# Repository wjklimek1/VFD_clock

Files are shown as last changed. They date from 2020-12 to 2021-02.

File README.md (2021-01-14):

# VFD_clock
Clock with VFD display based on STM32 MCU. Displays time, date and temperature.

As a display i used an old VFD tube IW-18 (IV-18). Device displays time (hours, minutes and seconds), date and temperature. Clock is based on STM32F103C8T6 microcontroller and it was programmed with HAL libraries. To boost voltage to required level I used popular SX1308 step-up IC.To power VFD display filament with alternating current i used L293d H-bridge with single transistor serving as simple NOT gate.

Schematic and PCB were designed using KiCad. You can find schematic in PDF format in PDFs folder of this repository.

Sensors used in the project:
RTC - DS3231 I2C real time clock

DS18B20 - 1-Wire temperature sensor (not utilized in software yet)
DHT11   - digital relative humidity sensor (not utilized in software yet)

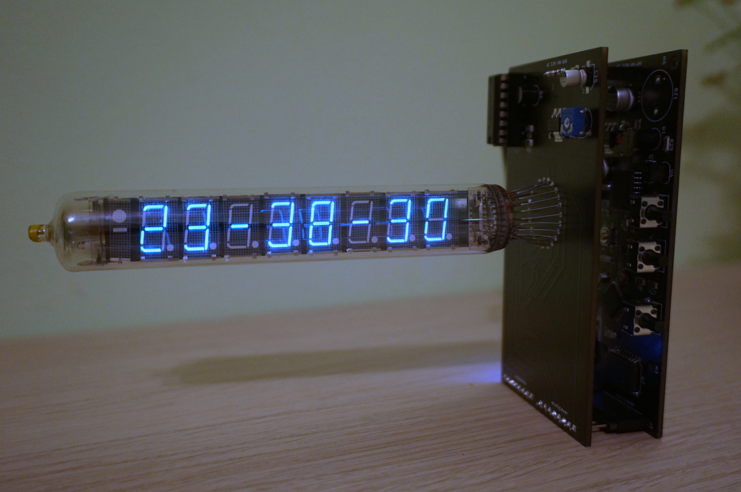
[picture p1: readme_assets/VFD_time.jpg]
VFD clock displaying time


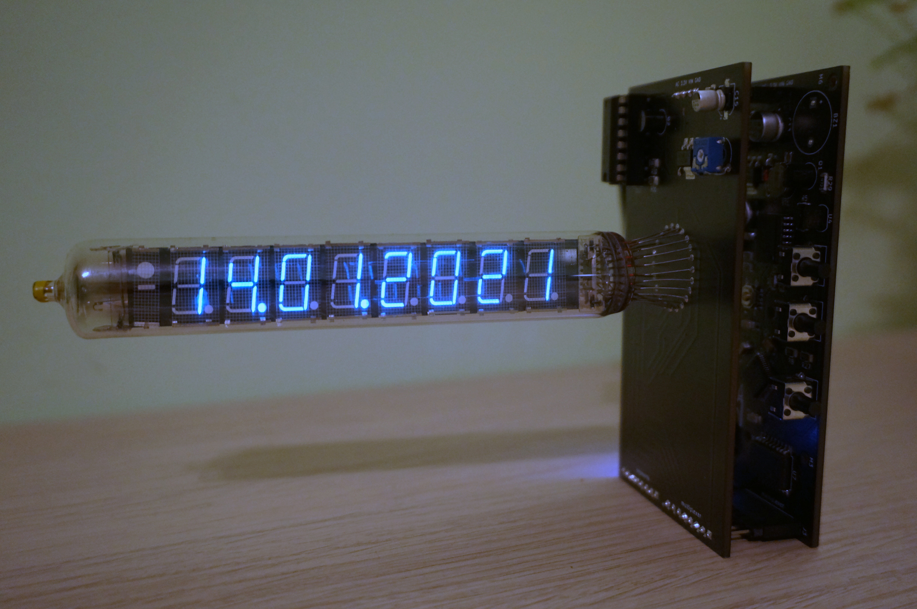
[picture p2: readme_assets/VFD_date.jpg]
VFD clock displaying date


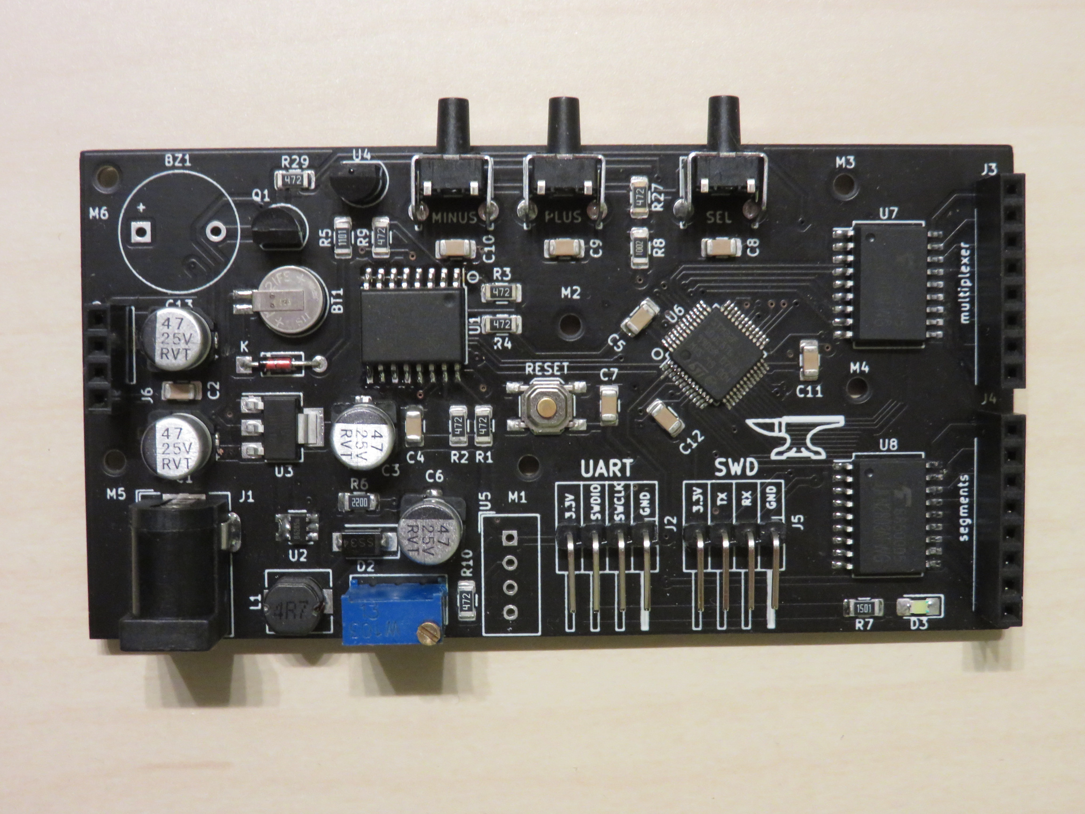
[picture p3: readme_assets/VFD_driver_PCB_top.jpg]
VFD clock driver PCB


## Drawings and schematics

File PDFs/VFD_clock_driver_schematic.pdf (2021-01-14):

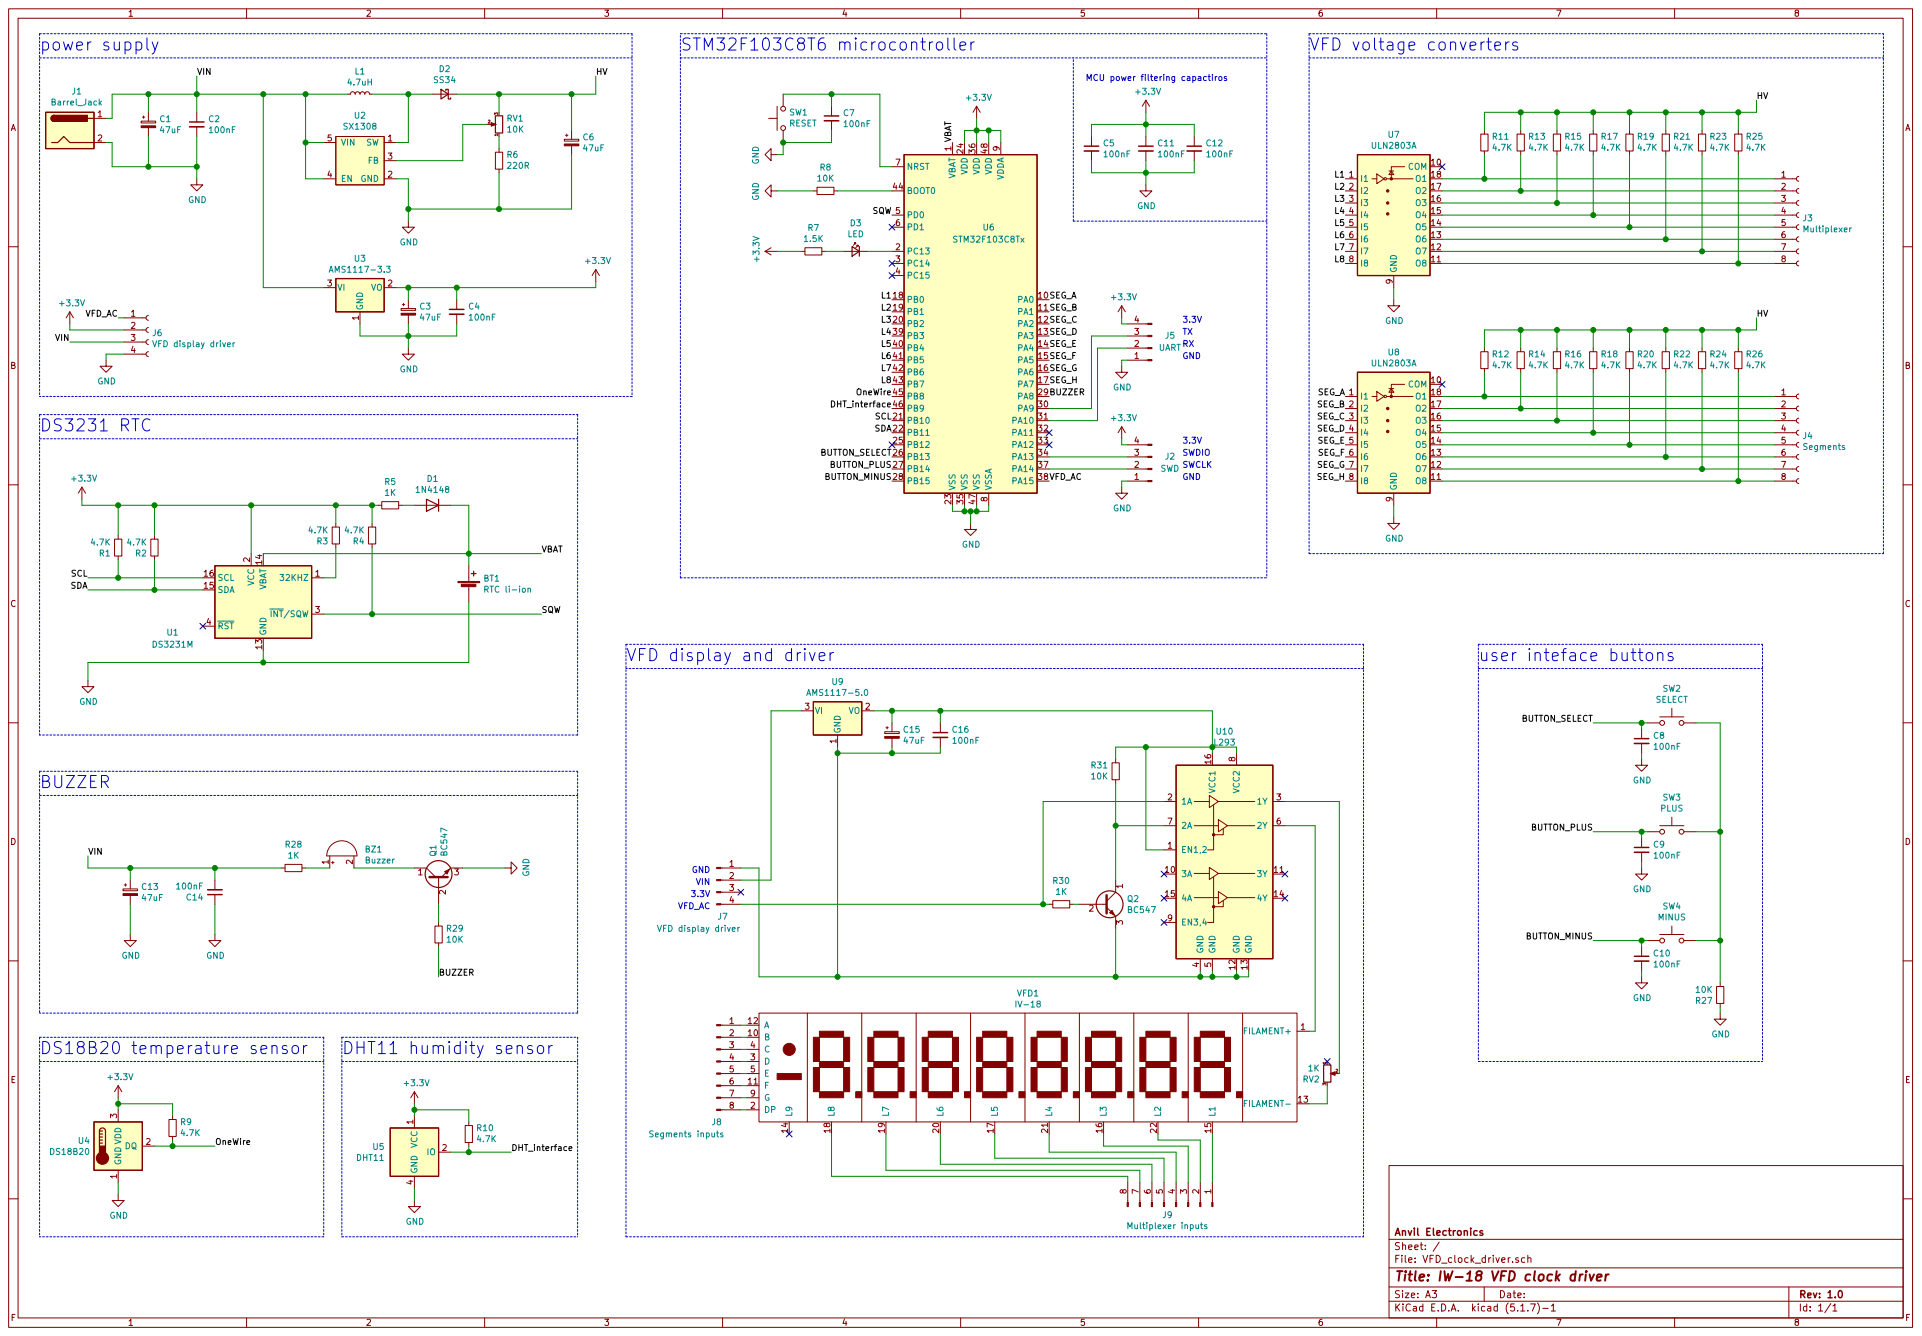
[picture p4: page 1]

MCU power filtering capactiros

1 VDD 24 VDD 36 VDD 48 VDDA

9 VSS 23 VSS 35 VSS 47 VSSA

File: VFD_clock_driver.sch Sheet: / Anvil Electronics

Id: 1/1 Title: IW-18 VFD clock driver

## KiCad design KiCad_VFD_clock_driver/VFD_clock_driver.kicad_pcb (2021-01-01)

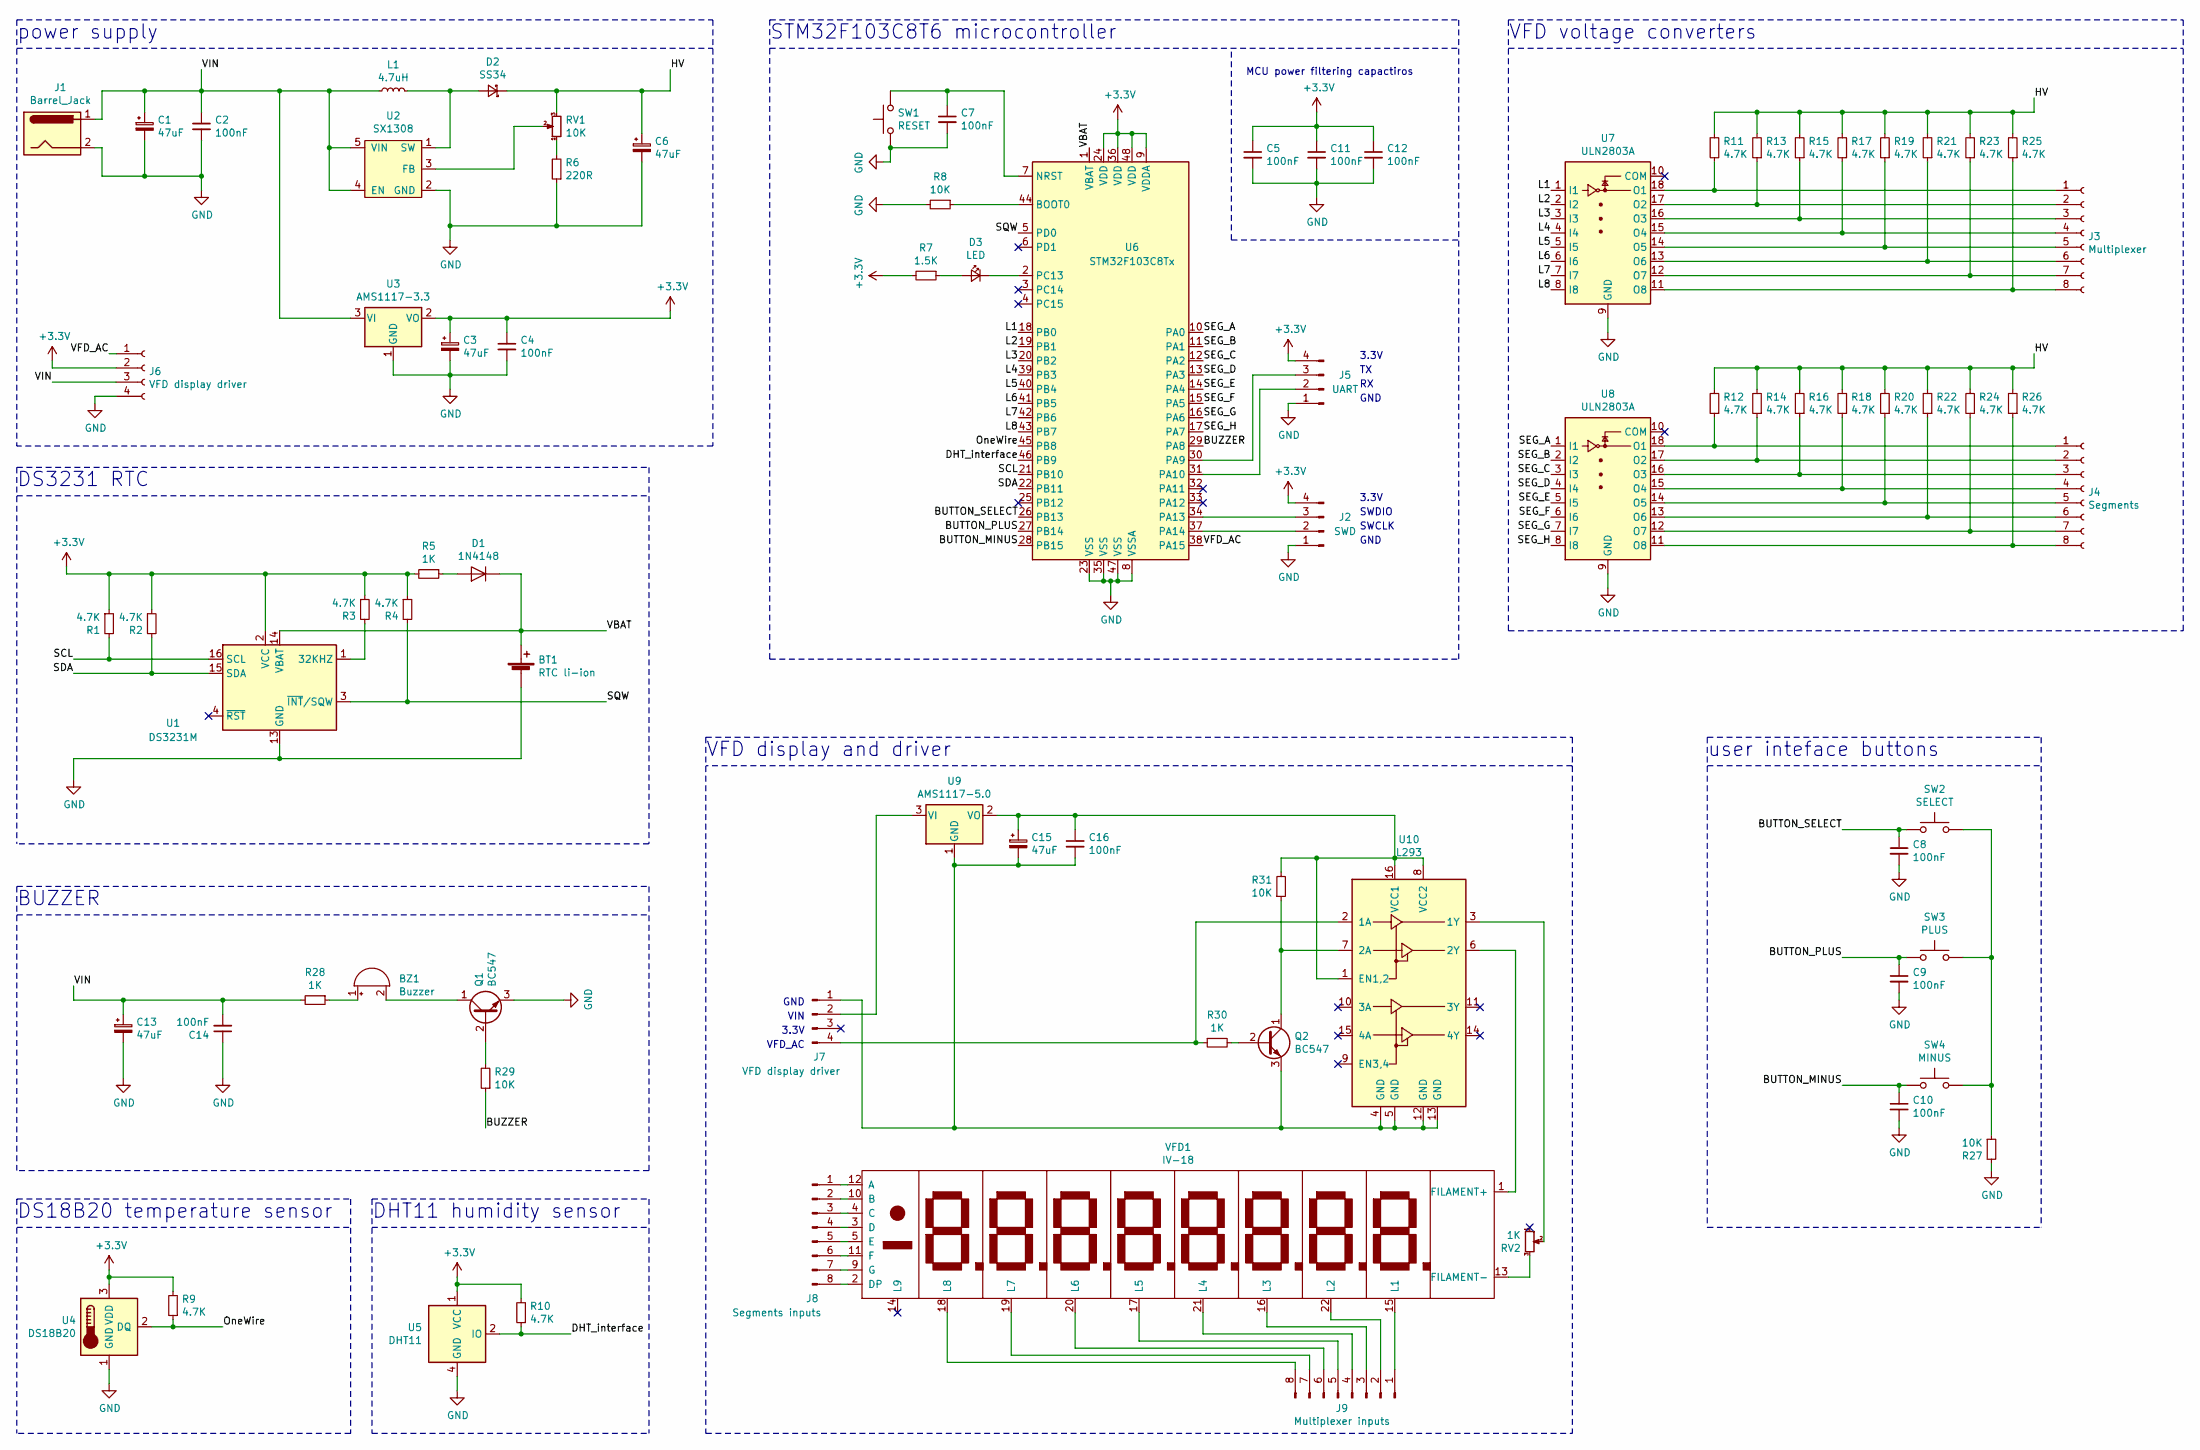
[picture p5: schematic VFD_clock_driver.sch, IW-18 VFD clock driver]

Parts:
BT1: RTC li-ion; BatteryHolder_Seiko_MS621F
BZ1: Buzzer; Buzzer_12x9.5RM7.6
C1, C3, C6, C13, C15: 47uF; CP_Elec_6.3x4.5
C2, C4, C5, C7, C8, C9, C10, C11, C12, C14, C16: 100nF; C_1206_3216Metric
D1: 1N4148; D_DO-35_SOD27_P7.62mm_Horizontal
D2: SS34; D_SMA
D3: LED; D_1206_3216Metric_Pad1.42x1.75mm_HandSolder
J1: Barrel_Jack; BarrelJack
J2: SWD; PinHeader_1x04_P2.54mm_Horizontal
J3: Multiplexer; PinSocket_1x08_P2.54mm_Vertical
J4: Segments; PinSocket_1x08_P2.54mm_Vertical
J5: UART; PinHeader_1x04_P2.54mm_Horizontal
J6: VFD display driver; PinSocket_1x04_P2.54mm_Vertical
J7: VFD display driver; PinHeader_1x04_P2.54mm_Vertical
J8: Segments inputs; PinHeader_1x08_P2.54mm_Vertical
J9: Multiplexer inputs; PinHeader_1x08_P2.54mm_Vertical
L1: 4.7uH; L_6.3x6.3_H3
Q1, Q2: BC547; TO-92_Inline
R1, R2, R3, R4, R9, R10, R11, R12, R13, R14, R15, R16, R17, R18, R19, R20, R21, R22, R23, R24, R25, R26: 4.7K; R_1206_3216Metric
R5, R28, R30: 1K; R_1206_3216Metric
R6: 220R; R_1206_3216Metric
R7: 1.5K; R_1206_3216Metric
R8, R27, R29, R31: 10K; R_1206_3216Metric
RV1: 10K; Potentiometer_Bourns_3296W_Vertical
RV2: 1K; Potentiometer_Piher_PT-6-V_Vertical_Hole
SW1: RESET; SW_SPST_TL3342
SW2: SELECT; SW_Tactile_SPST_Angled_PTS645Vx83-2LFS
SW3: PLUS; SW_Tactile_SPST_Angled_PTS645Vx83-2LFS
SW4: MINUS; SW_Tactile_SPST_Angled_PTS645Vx83-2LFS
U1: DS3231M; SOIC-16W_7.5x10.3mm_P1.27mm
U2: SX1308; SOT-23-6_Handsoldering
U3: AMS1117-3.3; SOT-223-3_TabPin2
U4: DS18B20; TO-92_Inline
U5: DHT11; Aosong_DHT11_5.5x12.0_P2.54mm
U6: STM32F103C8Tx; LQFP-48_7x7mm_P0.5mm
U7, U8: ULN2803A; SOP-18_7x12.5mm_P1.27mm
U9: AMS1117-5.0; SOT-223-3_TabPin2
U10: L293; DIP-16_W7.62mm
VFD1: IV-18

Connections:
+3V3: C3.1, C4.1, C5.1, C11.1, C12.1, J2.4, J5.4, J6.2, R1.1, R2.1, R3.1, R4.1, R5.2, R7.2, R9.2, R10.2, U1.2 (VCC), U3.2 (VO), U4.3 (VDD), U5.1 (VCC), U6.9 (VDDA), U6.24 (VDD), U6.36 (VDD), U6.48 (VDD)
/BUTTON_MINUS: C10.1, SW4.1, U6.28 (PB15)
/BUTTON_PLUS: C9.1, SW3.1, U6.27 (PB14)
/BUTTON_SELECT: C8.1, SW2.1, U6.26 (PB13)
/BUZZER: R29.1, U6.29 (PA8)
/DHT_interface: R10.1, U5.2 (IO), U6.46 (PB9)
/HV: C6.1, D2.1 (K), R11.2, R12.2, R13.2, R14.2, R15.2, R16.2, R17.2, R18.2, R19.2, R20.2, R21.2, R22.2, R23.2, R24.2, R25.2, R26.2, RV1.3
/L1: U6.18 (PB0), U7.1 (I1)
/L2: U6.19 (PB1), U7.2 (I2)
/L3: U6.20 (PB2), U7.3 (I3)
/L4: U6.39 (PB3), U7.4 (I4)
/L5: U6.40 (PB4), U7.5 (I5)
/L6: U6.41 (PB5), U7.6 (I6)
/L7: U6.42 (PB6), U7.7 (I7)
/L8: U6.43 (PB7), U7.8 (I8)
/OneWire: R9.1, U4.2 (DQ), U6.45 (PB8)
/SCL: R1.2, U1.16 (SCL), U6.21 (PB10)
/SDA: R2.2, U1.15 (SDA), U6.22 (PB11)
/SEG_A: U6.10 (PA0), U8.1 (I1)
/SEG_B: U6.11 (PA1), U8.2 (I2)
/SEG_C: U6.12 (PA2), U8.3 (I3)
/SEG_D: U6.13 (PA3), U8.4 (I4)
/SEG_E: U6.14 (PA4), U8.5 (I5)
/SEG_F: U6.15 (PA5), U8.6 (I6)
/SEG_G: U6.16 (PA6), U8.7 (I7)
/SEG_H: U6.17 (PA7), U8.8 (I8)
/SQW: R4.2, U1.3 (~INT~/SQW), U6.5 (PD0)
/VBAT: BT1.1 (+), D1.1 (K), U1.14 (VBAT), U6.1 (VBAT)
/VFD_AC: J6.1, U6.38 (PA15)
/VIN: C1.1, C2.1, C13.1, C14.2, J1.1, J6.3, L1.1, R28.2, U2.4 (EN), U2.5 (VIN), U3.3 (VI)
GND: BT1.2 (-), C1.2, C2.2, C3.2, C4.2, C5.2, C6.2, C7.2, C8.2, C9.2, C10.2, C11.2, C12.2, C13.2, C14.1, J1.2, J2.1, J5.1, J6.4, Q1.3 (E), R6.1, R8.2, R27.2, SW1.1, U1.5 (GND), U1.6 (GND), U1.7 (GND), U1.8 (GND), U1.9 (GND), U1.10 (GND), U1.11 (GND), U1.12 (GND), U1.13 (GND), U2.2 (GND), U3.1 (GND), U4.1 (GND), U5.4 (GND), U6.8 (VSSA), U6.23 (VSS), U6.35 (VSS), U6.47 (VSS), U7.9 (GND), U8.9 (GND)
unnamed: BZ1.1 (-), R28.1
unnamed: BZ1.2 (+), Q1.1 (C)
unnamed: C7.1, SW1.2, U6.7 (NRST)
unnamed: C15.1, C16.1, R31.2, U9.2 (VO), U10.1 (EN1,2), U10.8 (VCC2), U10.16 (VCC1)
unnamed: C15.2, C16.2, J7.1, Q2.3 (E), U9.1 (GND), U10.4 (GND), U10.5 (GND), U10.12 (GND), U10.13 (GND)
unnamed: D1.2 (A), R5.1
unnamed: D2.2 (A), L1.2, U2.1 (SW)
unnamed: D3.1 (K), U6.2 (PC13)
unnamed: D3.2 (A), R7.1
unnamed: J2.2, U6.37 (PA14)
unnamed: J2.3, U6.34 (PA13)
unnamed: J3.1, R11.1, U7.18 (O1)
unnamed: J3.2, R13.1, U7.17 (O2)
unnamed: J3.3, R15.1, U7.16 (O3)
unnamed: J3.4, R17.1, U7.15 (O4)
unnamed: J3.5, R19.1, U7.14 (O5)
unnamed: J3.6, R21.1, U7.13 (O6)
unnamed: J3.7, R23.1, U7.12 (O7)
unnamed: J3.8, R25.1, U7.11 (O8)
unnamed: J4.1, R12.1, U8.18 (O1)
unnamed: J4.2, R14.1, U8.17 (O2)
unnamed: J4.3, R16.1, U8.16 (O3)
unnamed: J4.4, R18.1, U8.15 (O4)
unnamed: J4.5, R20.1, U8.14 (O5)
unnamed: J4.6, R22.1, U8.13 (O6)
unnamed: J4.7, R24.1, U8.12 (O7)
unnamed: J4.8, R26.1, U8.11 (O8)
unnamed: J5.2, U6.31 (PA10)
unnamed: J5.3, U6.30 (PA9)
unnamed: J7.2, U9.3 (VI)
unnamed: J7.4, R30.1, U10.2 (1A)
unnamed: J8.1, VFD1.12 (A)
unnamed: J8.2, VFD1.10 (B)
unnamed: J8.3, VFD1.4 (C)
unnamed: J8.4, VFD1.3 (D)
unnamed: J8.5, VFD1.5 (E)
unnamed: J8.6, VFD1.11 (F)
unnamed: J8.7, VFD1.9 (G)
unnamed: J8.8, VFD1.2 (DP)
unnamed: J9.1, VFD1.15 (L1)
unnamed: J9.2, VFD1.22 (L2)
unnamed: J9.3, VFD1.16 (L3)
unnamed: J9.4, VFD1.21 (L4)
unnamed: J9.5, VFD1.17 (L5)
unnamed: J9.6, VFD1.20 (L6)
unnamed: J9.7, VFD1.19 (L7)
unnamed: J9.8, VFD1.18 (L8)
unnamed: Q1.2 (B), R29.2
unnamed: Q2.1 (C), R31.1, U10.7 (2A)
unnamed: Q2.2 (B), R30.2
unnamed: R3.2, U1.1 (32KHZ)
unnamed: R6.2, RV1.1
unnamed: R8.1, U6.44 (BOOT0)
unnamed: R27.1, SW2.2, SW3.2, SW4.2
unnamed: RV1.2, U2.3 (FB)
unnamed: RV2.2, U10.3 (1Y)
unnamed: RV2.3, VFD1.13 (FILAMENT-)
unnamed: U10.6 (2Y), VFD1.1 (FILAMENT+)

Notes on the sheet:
3.3V
SWDIO
SWCLK
GND
DS3231 RTC
power supply
DS18B20 temperature sensor
VFD voltage converters
user inteface buttons
DHT11 humidity sensor
STM32F103C8T6 microcontroller
MCU power filtering capactiros
BUZZER
VIN
VFD_AC
VFD display and driver

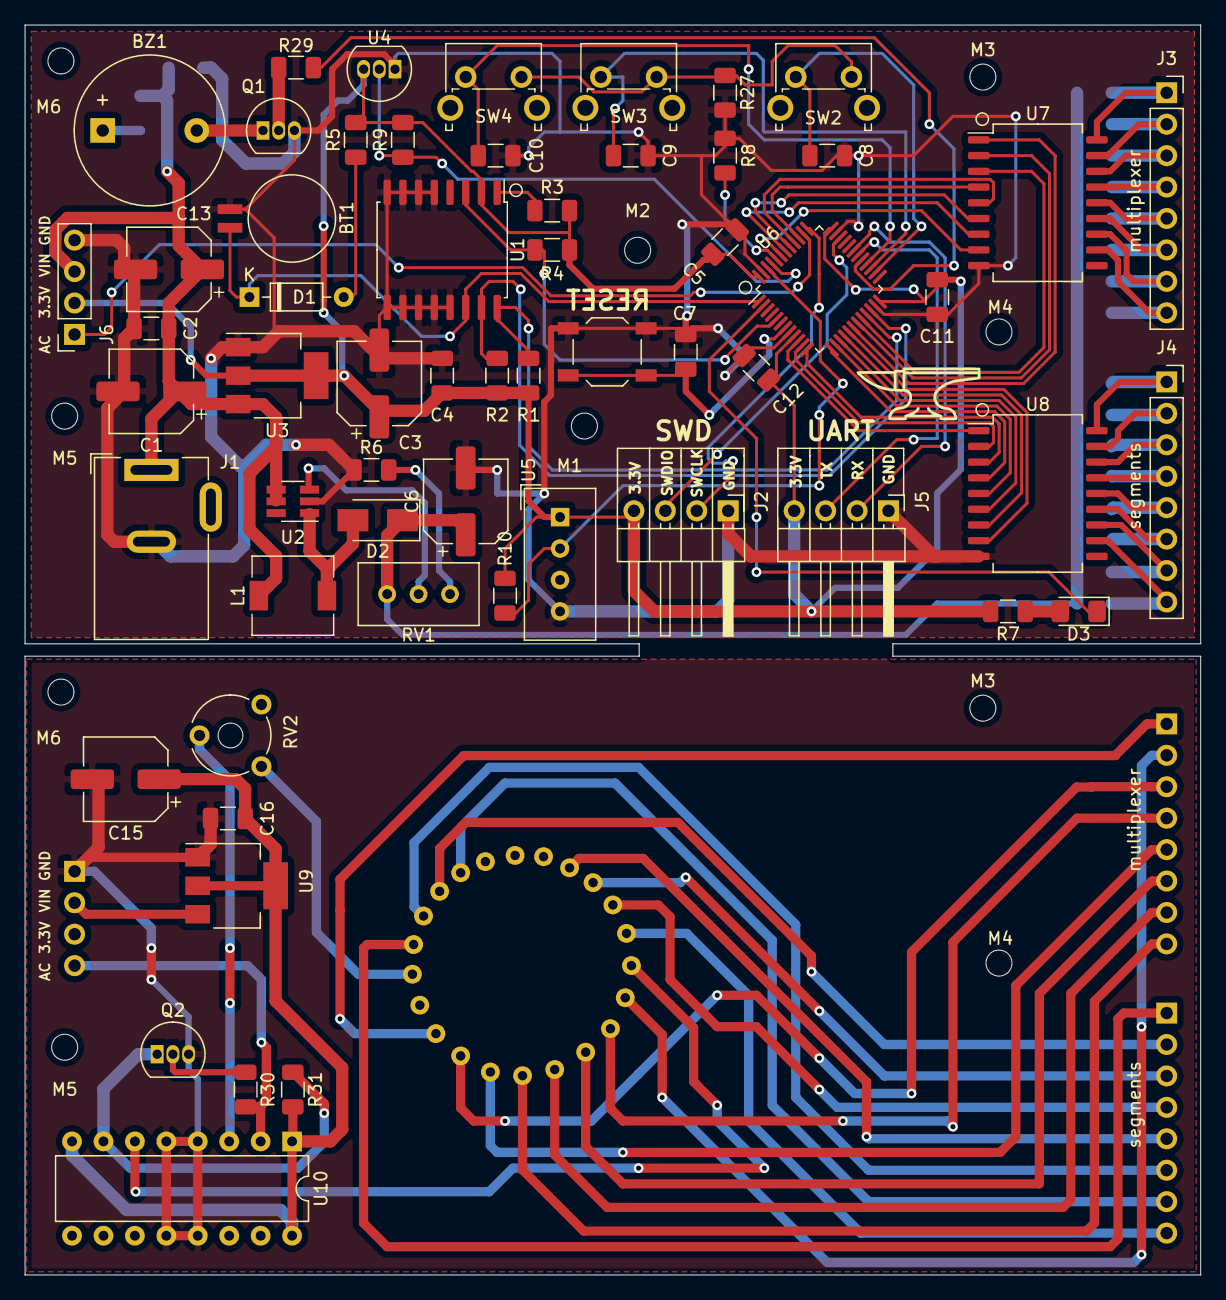
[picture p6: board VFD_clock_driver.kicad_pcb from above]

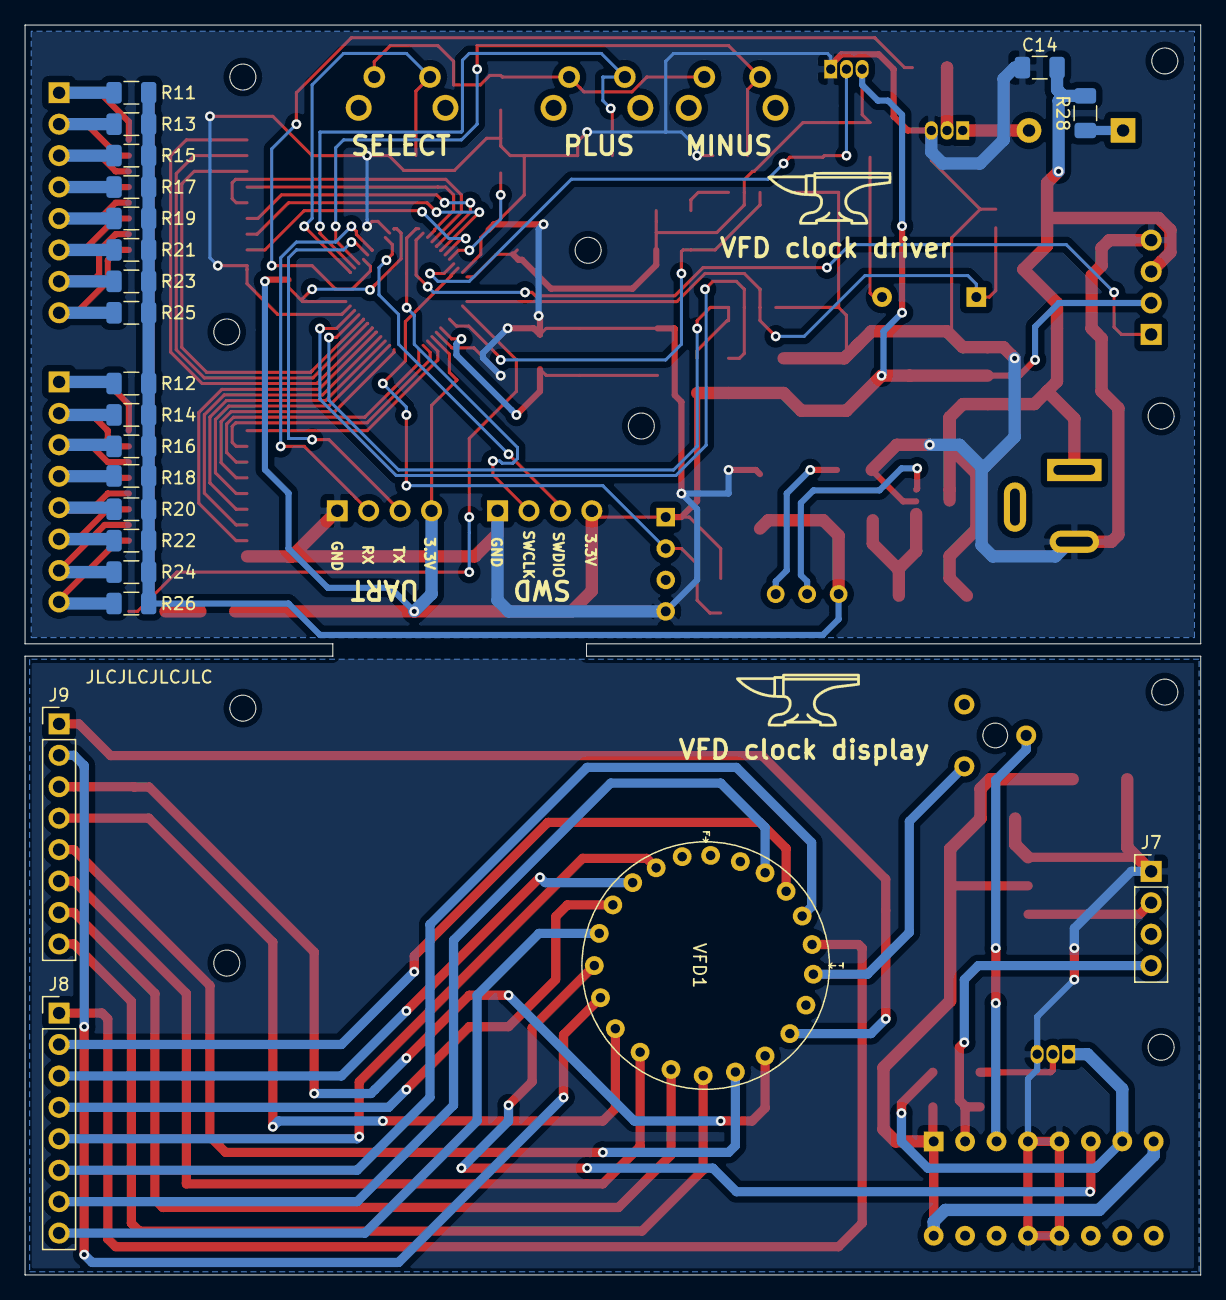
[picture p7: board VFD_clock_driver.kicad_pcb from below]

Board: 2 copper layers, 95.0 x 101.0 mm, 91 parts (22 on the bottom side), 89 nets.

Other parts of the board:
M1, M2, M3, M3#2, M4, M4#2, M5, M5#2, M6, M6#2: MountingHole_2.1mm

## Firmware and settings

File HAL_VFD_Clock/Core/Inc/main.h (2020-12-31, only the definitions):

#define LED_Pin GPIO_PIN_13
#define LED_GPIO_Port GPIOC
#define SQW_Pin GPIO_PIN_0
#define SQW_GPIO_Port GPIOD
#define SQW_EXTI_IRQn EXTI0_IRQn
#define SEG_A_Pin GPIO_PIN_0
#define SEG_A_GPIO_Port GPIOA
#define SEG_B_Pin GPIO_PIN_1
#define SEG_B_GPIO_Port GPIOA
#define SEG_C_Pin GPIO_PIN_2
#define SEG_C_GPIO_Port GPIOA
#define SEG_D_Pin GPIO_PIN_3
#define SEG_D_GPIO_Port GPIOA
#define SEG_E_Pin GPIO_PIN_4
#define SEG_E_GPIO_Port GPIOA
#define SEG_F_Pin GPIO_PIN_5
#define SEG_F_GPIO_Port GPIOA
#define SEG_G_Pin GPIO_PIN_6
#define SEG_G_GPIO_Port GPIOA
#define SEG_H_Pin GPIO_PIN_7
#define SEG_H_GPIO_Port GPIOA
#define L1_Pin GPIO_PIN_0
#define L1_GPIO_Port GPIOB
#define L2_Pin GPIO_PIN_1
#define L2_GPIO_Port GPIOB
#define L3_Pin GPIO_PIN_2
#define L3_GPIO_Port GPIOB
#define BUTTON_SELECT_Pin GPIO_PIN_13
#define BUTTON_SELECT_GPIO_Port GPIOB
#define BUTTON_SELECT_EXTI_IRQn EXTI15_10_IRQn
#define BUTTON_PLUS_Pin GPIO_PIN_14
#define BUTTON_PLUS_GPIO_Port GPIOB
#define BUTTON_PLUS_EXTI_IRQn EXTI15_10_IRQn
#define BUTTON_MINUS_Pin GPIO_PIN_15
#define BUTTON_MINUS_GPIO_Port GPIOB
#define BUTTON_MINUS_EXTI_IRQn EXTI15_10_IRQn
#define BUZZER_Pin GPIO_PIN_8
#define BUZZER_GPIO_Port GPIOA
#define VFD_AC_Pin GPIO_PIN_15
#define VFD_AC_GPIO_Port GPIOA
#define L4_Pin GPIO_PIN_3
#define L4_GPIO_Port GPIOB
#define L5_Pin GPIO_PIN_4
#define L5_GPIO_Port GPIOB
#define L6_Pin GPIO_PIN_5
#define L6_GPIO_Port GPIOB
#define L7_Pin GPIO_PIN_6
#define L7_GPIO_Port GPIOB
#define L8_Pin GPIO_PIN_7
#define L8_GPIO_Port GPIOB
#define DHT_interface_Pin GPIO_PIN_8
#define DHT_interface_GPIO_Port GPIOB
#define OneWire_Pin GPIO_PIN_9
#define OneWire_GPIO_Port GPIOB

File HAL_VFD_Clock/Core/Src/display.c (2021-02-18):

#include "display.h"

/*
 * @brief Outputs character mask on segments
 *
 * Bits in symbol_mask byte represents powered segments in following order:
 * ABCDEFGH
 *
 * @param[in]
 * symbol_mask 8bit mask of GPIO pins states
 */
void dispChar(uint8_t symbol_mask)
{
	SEGMENTS_GPIO_Port->BSRR = ~symbol_mask;
	SEGMENTS_GPIO_Port->BSRR = symbol_mask << 16u;
}

/*
 * @brief Activates displays in VFD tube
 *
 * bits in displays_mask byte represents powered displays in following order:
 * LSB - far right display
 * MSB - far left display
 *
 * @param[in] displays_mask 8bit mask where one bit is 1 and others are 0. Active bit codes number of activated display.
 */
void selectDisplay(uint8_t displays_mask)
{
	DISPLAYS_GPIO_Port->BSRR = ~displays_mask;
	DISPLAYS_GPIO_Port->BSRR = displays_mask << 16u;
}

/*
 * @brief Multiplexer function that is supposed to be used in regular intervals triggered by timer.
 *
 * It iterates through array of masks of characters that will be displayed. In a single cycle only one display is
 * activated. After 8 cycles it starts again from beginning of masks array.
 *
 * blink_timer is incremented every cycle by 64 and if it is lower than half of its max value,
 * blink_mask is taken into consideration and display which corresponding bit in blink_mask is 0 will be turned off.
 */
void multiplexerSequence()
{
	static uint8_t i = 0;              //number of currently active display
	static uint16_t blink_timer = 0;   //

	dispChar(tab_to_display[i]);        //set GPIOs to states described in corresponding mask in array
	if(blink_timer > (0xFFFF / 2))      //decide if digit should blink
		selectDisplay(1U << i);         //display digit normally
	else
		selectDisplay((1U << i) & blink_mask); //if digit is masked by bit in blink_mask
	                                           //and blink timer hasn't elapsed half of its max value, disable display

	++i;                //increment number of currently active display
	blink_timer += 64;  //increment blink timer

	if(i >= 8)          //if last display was handled, move back to first one
		i = 0;
}

/*
 * @brief Converts ASCII character to corresponding 7 segment display bitmask
 *
 * If character is undefined, it returns empty mask (space).
 *
 * @param[in] inputChar ASCII character
 * @returns 8bit bitmask for 7 segment display
 */

uint8_t charToBitmask(char inputChar)
{
	switch (inputChar)
	{
		// numbers masks
		case '1':
			return mask_1;
		case '2':
			return mask_2;
		case '3':
			return mask_3;
		case '4':
			return mask_4;
		case '5':
			return mask_5;
		case '6':
			return mask_6;
		case '7':
			return mask_7;
		case '8':
			return mask_8;
		case '9':
			return mask_9;
		case '0':
			return mask_0;

			//special masks
		case ' ':
			return mask_space;
		case '-':
			return mask_hypen;
		case '*':
			return mask_degree;

			//characters masks
		case 'a':
			return mask_A;
		case 'b':
			return mask_B;
		case 'c':
			return mask_C;
		case 'd':
			return mask_D;
		case 'e':
			return mask_E;
		case 'f':
			return mask_F;
		case 'h':
			return mask_H;
		case 'i':
			return mask_I;
		case 'j':
			return mask_J;
		case 'l':
			return mask_L;
		case 'o':
			return mask_O;
		case 'p':
			return mask_P;
		case 'r':
			return mask_R;
		case 's':
			return mask_S;
		case 't':
			return mask_T;
		case 'u':
			return mask_U;
		default:
			return 0;
	}
}

/*
 * @brief Converts single digit to bitmask
 *
 * @param[in] digit single digit that will be converted to corresponding mask
 */
uint8_t digitToBitmask(uint8_t digit)
{
	if(digit > 9)
		return 0b00000000;
	switch (digit)
	{
		case 1:
			return mask_1;
		case 2:
			return mask_2;
		case 3:
			return mask_3;
		case 4:
			return mask_4;
		case 5:
			return mask_5;
		case 6:
			return mask_6;
		case 7:
			return mask_7;
		case 8:
			return mask_8;
		case 9:
			return mask_9;
		case 0:
			return mask_0;
		default:
			return 0;
	}
}

/*
 * @brief Converts string to array of bitmasks
 *
 * String has to be null-terminated!
 *
 * @param[in] string pointer to char array
 * @param[in] pos empty spaces to leave in masks array before first character string.
 */
void dispString(const char *string, uint8_t pos)
{
	if(pos > 7)
		return;
	while (*string)
	{
		tab_to_display[pos] = charToBitmask(*string);
		string++;
		pos--;

		if(pos < 0)
			return;
	}
}

/*
 * @brief Displays time in following format: HH-MM-SS
 *
 * @param[in] hour - hour to display. If value is smaller than 0 then only single digit is displayed
 * @param[in] minute - number of minutes to display
 * @param[in] second - number of seconds to display
 */
void displayHour(uint8_t hour, uint8_t minute, uint8_t second)
{
	// hide 0 if hour digit is smaller than 10
	if(hour / 10 == 0)
		tab_to_display[7] = 0b00000000;
	else
		tab_to_display[7] = digitToBitmask(hour / 10);

	tab_to_display[6] = digitToBitmask(hour % 10);
	tab_to_display[5] = mask_hypen;
	tab_to_display[4] = digitToBitmask(minute / 10);
	tab_to_display[3] = digitToBitmask(minute % 10);
	tab_to_display[2] = mask_hypen;
	tab_to_display[1] = digitToBitmask(second / 10);
	tab_to_display[0] = digitToBitmask(second % 10);
}

/*
 * @brief Displays date in following format: DD.MM.YYYY
 *
 * @param[in] day - number of day of month
 * @param[in] month - number of month (1-January ... 12-December)
 * @param[in] year - last two digits of year. Assuming year is after 2000 and before 2100 :D
 */
void displayDate(uint8_t day, uint8_t month, uint8_t year)
{
	// hide 0 if day number is smaller than 10
	if(day / 10 == 0)
		tab_to_display[7] = 0b00000000;
	else
		tab_to_display[7] = digitToBitmask(day / 10);

	tab_to_display[6] = digitToBitmask(day % 10);
	tab_to_display[5] = digitToBitmask(month / 10);
	tab_to_display[4] = digitToBitmask(month % 10);
	tab_to_display[3] = mask_2;
	tab_to_display[2] = mask_0;
	tab_to_display[1] = digitToBitmask(year / 10);
	tab_to_display[0] = digitToBitmask(year % 10);

	tab_to_display[6] |= mask_dot;
	tab_to_display[4] |= mask_dot;
}

/*
 * @brief Displays temperature with two decimal points precision and Celcius degree symbol.
 *
 * Displaying format is: " TT.TT *C "
 *
 * @param[in] temperature to display
 */
void displayTemperature(float temperature)
{
	uint8_t temperature_integer = (uint8_t) temperature;
	uint8_t temperature_fraction = (uint8_t) ((temperature - temperature_integer) * 100);

	tab_to_display[7] = 0;
	tab_to_display[6] = digitToBitmask(temperature_integer / 10);
	tab_to_display[5] = digitToBitmask(temperature_integer % 10);
	tab_to_display[5] |= mask_dot;
	tab_to_display[4] = digitToBitmask(temperature_fraction / 10);
	tab_to_display[3] = digitToBitmask(temperature_fraction % 10);
	tab_to_display[2] = charToBitmask('*');
	tab_to_display[1] = charToBitmask('c');
	tab_to_display[0] = 0;

}

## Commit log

2020-07-14 Initial driver schematic
    + initial driver schematic
    + added project description to readme.md
    + added .gitignore
    [VFD_clock_driver.kicad_pcb, VFD_clock_driver.sch]
2020-11-17 Final driver schematic
    Final driver PCB schematic
    [VFD_clock_driver.kicad_pcb, VFD_clock_driver.sch]
2020-11-17 Buzzer and additional inputs
    + added buzzer with circuitry
    + SQW and UART connected to MCU
    [VFD_clock_driver.kicad_pcb, VFD_clock_driver.sch]
2020-11-19 Power supply section in PCB
    [VFD_clock_driver.kicad_pcb, VFD_clock_driver.sch]
2020-11-19 Final PCB routing
    + updated gitignore with some unnecessary KiCad files
    + final component placement on BCB
    + final routing on PCB
    [VFD_clock_driver.kicad_pcb]
2020-11-19 Silkscreen and planes on PCB
    + final silkscreen on PCB
    + small routing and component location tweaks
    + GND planes on PCB
    [VFD_clock_driver.kicad_pcb]
2020-11-19 VFD tube power connector on BCB
    [VFD_clock_driver.kicad_pcb, VFD_clock_driver.sch]
2020-11-23 External PCB for VFD tube and H-brigde
    + additional PCB for VFD tube with H-bridge
    [VFD_clock_driver.kicad_pcb, VFD_clock_driver.sch]
2020-11-24 Mounting holes on tube PCB
    + added mounting holed on tube PCB, new holes are aligned with old ones in driver PCB
    + fixed misplaced UART and SWD connectors descriptions on silkscreen
    [VFD_clock_driver.kicad_pcb]
2021-01-01 Changes in footprints, changed VCC pin in SX1308
    + changed polarized capacitors footprints to biiger ones
    + changed SX1308 footprint to 6 legged version
    + changed logic VCC for L293 from 3.3V to 5V
    [VFD_clock_driver.kicad_pcb, VFD_clock_driver.sch]
2021-01-01 VFD display multiplexing
    + added multiplexing on TIM3 timer interrupt running with 1kHz frequency
    + added bit masks for various characters
    + migrtion to new CubeIDE version 1.5.1
2021-01-14 Buttons EXTI callbacks, date and time displaying
    + implemented buttons EXTI Callback
    + implemented functions displaying date and time
2021-01-14 Time setting with buttons
    + setting time with flags, state machine and watchdog
    + blinking mask used to blink selected displays in multiplexer sequence
2021-01-14 Date setting with buttons
    + setting date in a way similar to setting time
    - function doesn't check number of days in given month what can lead to errors in saving time to RTC
2021-01-14 Changes in README and PDF schematic
    + added schematic in PDF format
    + changes in readme.md
2021-01-14 Images of real device in readme
2021-02-15 Clamp day range to number of days in current month
    + added function that checks number of days in current month and year
    + number of days in menu is clamped to correct number of days in current month and year
    + added some comments to function selecting time
    + when month gets decremented below 1 is changed for 12 instead of freezing
2021-02-16 Internal temperature display at startup
    + displaying internal circuit temperature from RTC at startup
    + fixed leading zeros flashing in hours and days
    [display.c]
2021-02-18 Function prototypes in main.c and multiplexer optimization
    + added function prototypes in main.c file and moved main() to top
    + optimization and comments in MultiplexerSequence()

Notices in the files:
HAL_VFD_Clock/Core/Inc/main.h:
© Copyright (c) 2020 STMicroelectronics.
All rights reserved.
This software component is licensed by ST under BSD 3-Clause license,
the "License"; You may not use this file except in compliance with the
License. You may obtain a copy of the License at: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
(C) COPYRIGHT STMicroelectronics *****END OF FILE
